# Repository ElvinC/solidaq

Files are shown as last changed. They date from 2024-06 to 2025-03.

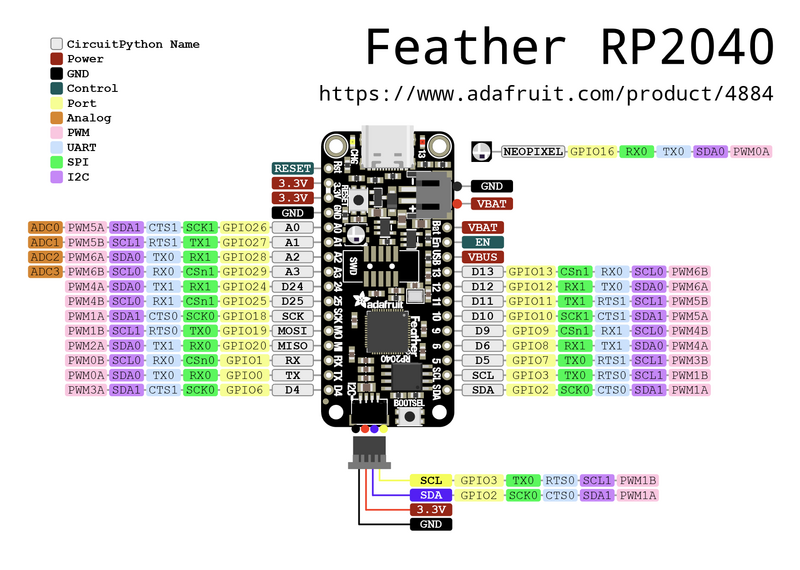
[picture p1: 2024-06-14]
Hardware/adafruit_products_feather-rp2040-pins.png

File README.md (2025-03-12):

# SoliDAQ

Super basic ADC/data logger board based on an Adafruit feather rp2040 dev board and an AD7124-4 24-bit ADC.

## Data storage format

```
typedef struct SensorLog {
    uint8_t header; // 'S' = 0x53. Keep track of used memory
    uint8_t log_id; // Log ID and marker for used memory.
    uint32_t time; // Time in ms
    int16_t adc_temp; // Cold junction temp in 0.01 deg celsius
    int16_t core_temp; // rp2040 temp in 0.01 deg celsius
    int32_t lc; // Loadcell, ratiometric in millionth (0.000001)
    int32_t tc1; // Thermocouple 1, value in nanovolts
    int32_t tc2; // Thermocouple 2, value in nanovolts
    int32_t ps; // 4-20 mA pressure. Value in nanoamps
    uint8_t delta_time;
    uint8_t log_percent; // Percent of the log that is full
    uint16_t vbat; // Battery voltage in 0.01V
} sensor_log_t;
```

csv representation example:

```
id,time[ms],tref[C],lc[mV/V],tc1[C],tc2[C],ps[mA]              
1,1374,21.0,0.670,32.8,20.7,-0.004       
```

With 32 megabytes of memory: 2.7 hours of logging time.

## USB Drive mode

The device emulates a FAT16 filesystem.

Some android phones can't open this natively. You can use e.g. the ZUGate app to connect to it.

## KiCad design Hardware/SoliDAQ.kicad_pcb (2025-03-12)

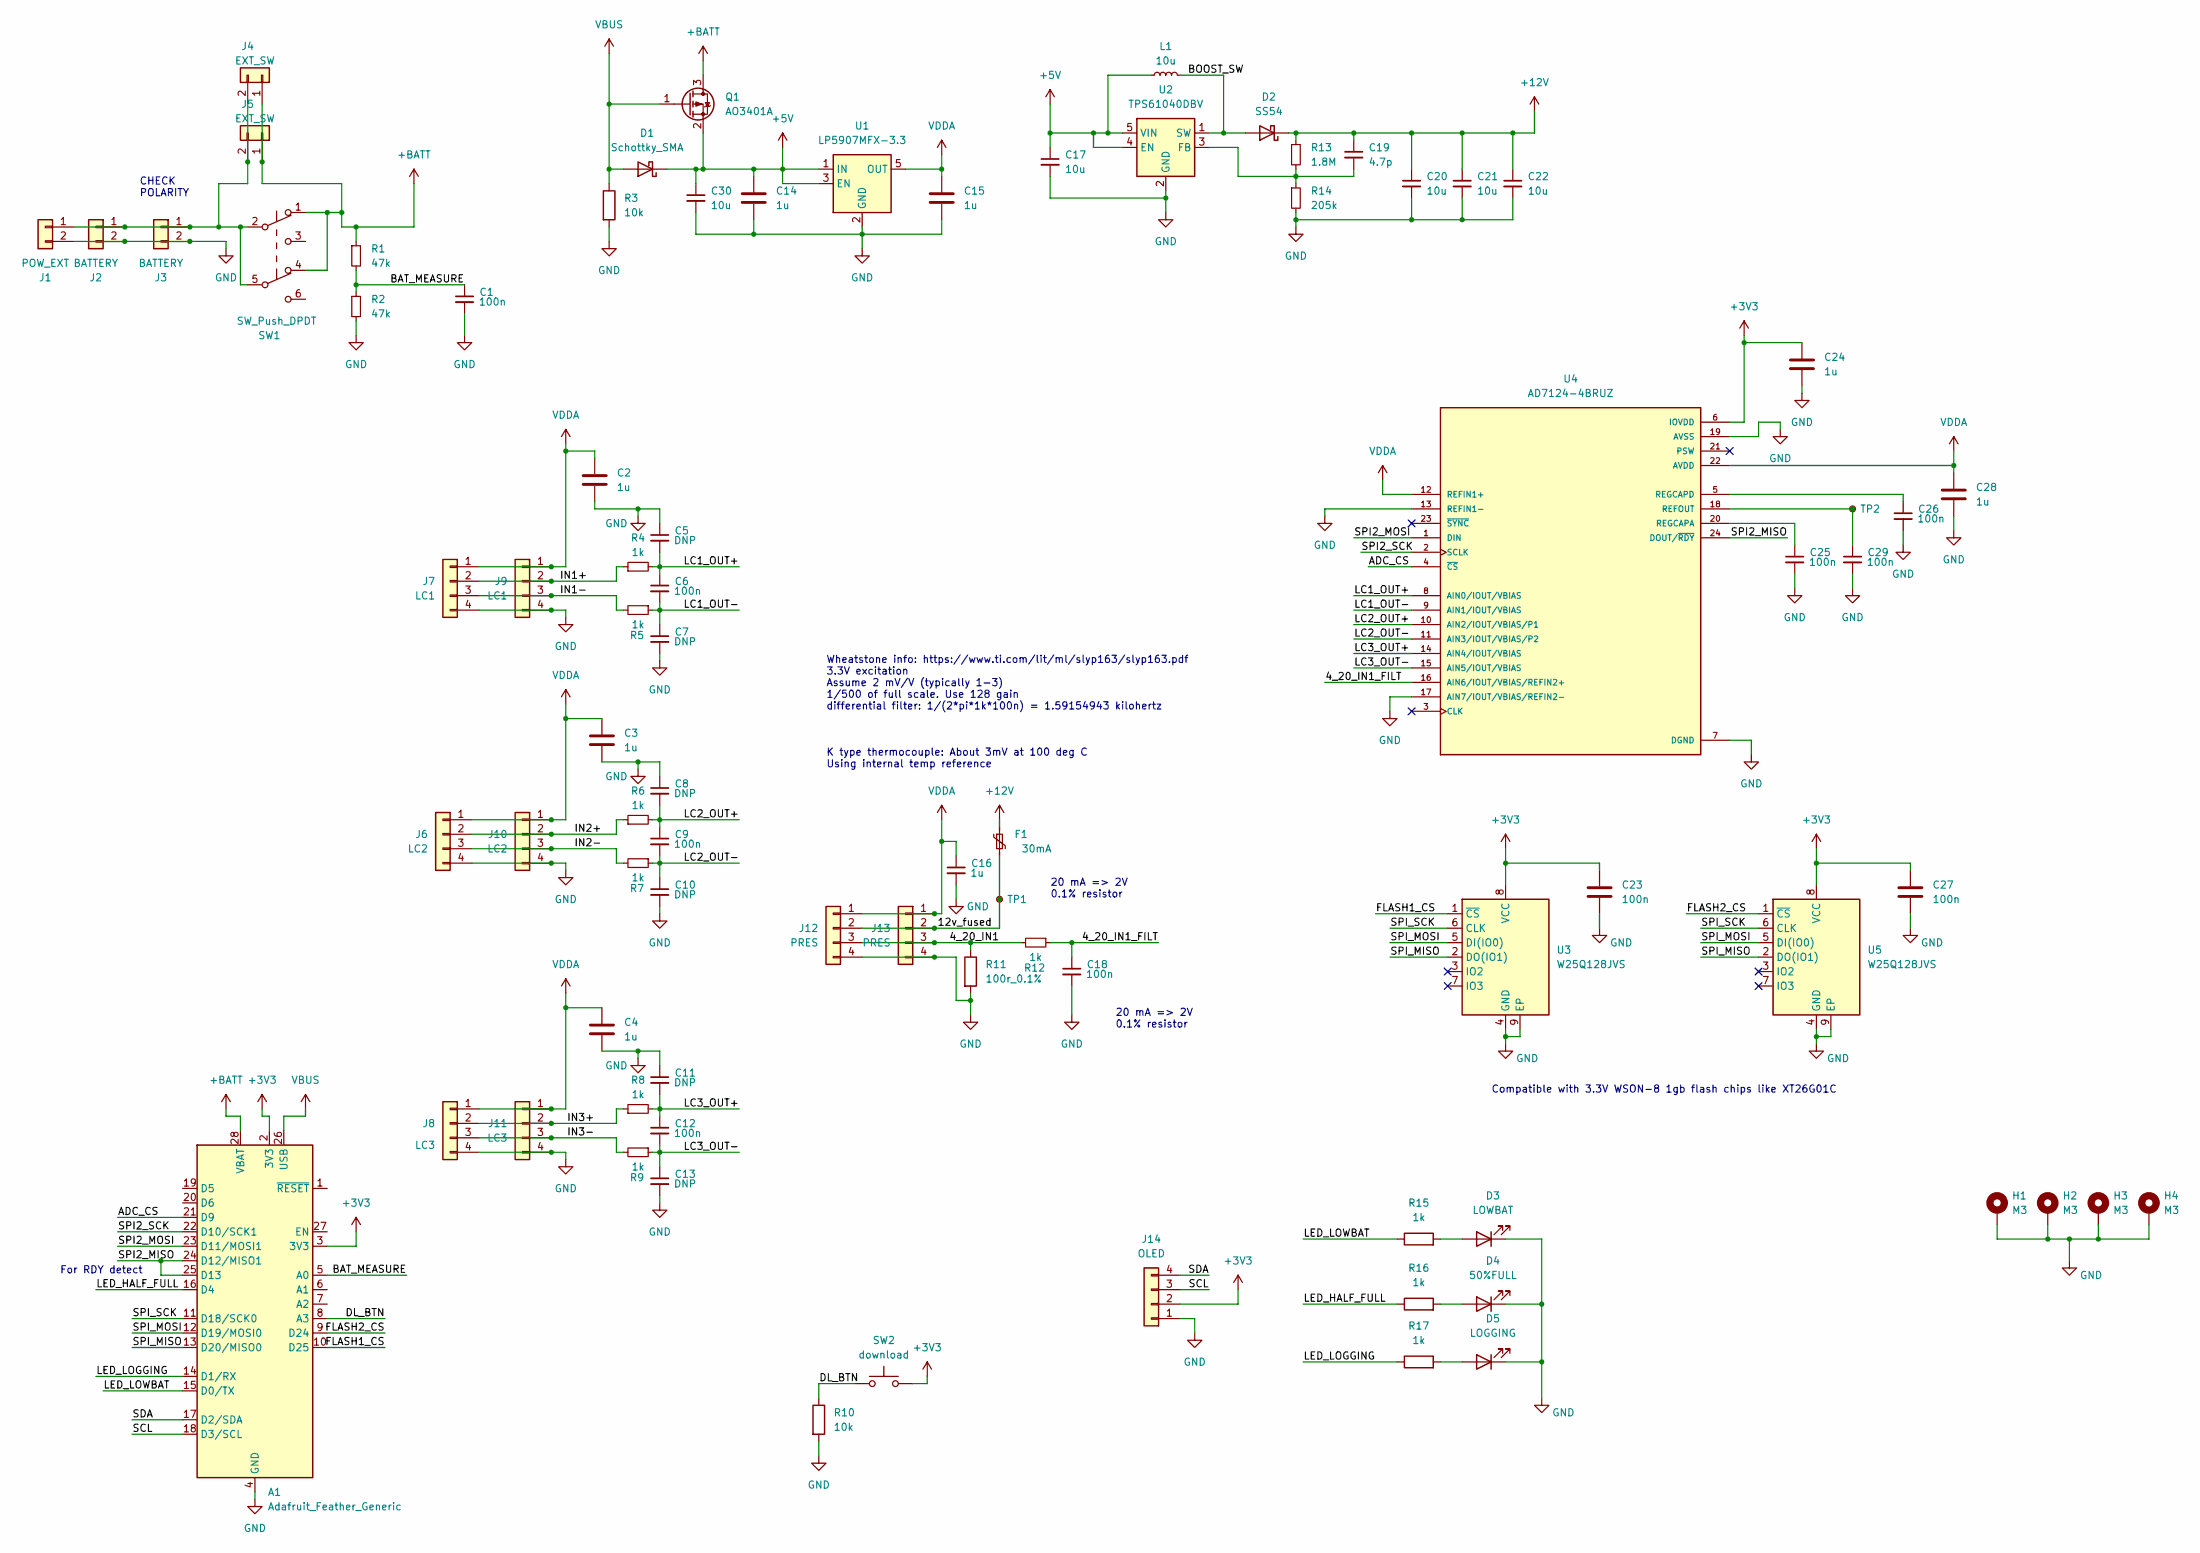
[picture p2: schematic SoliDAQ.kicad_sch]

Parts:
A1: Adafruit_Feather_Generic; Adafruit_Feather
C1, C6, C9, C12, C18, C23, C25, C26, C27, C29: 100n; C_0603_1608Metric
C2, C3, C4, C14, C15, C16, C24, C28: 1u; C_0603_1608Metric
C5, C7, C8, C10, C11, C13: DNP; C_0603_1608Metric
C17, C20, C21, C22, C30: 10u; C_0805_2012Metric
C19: 4.7p; C_0603_1608Metric
D1: Schottky_SMA; D_SMA
D2: SS54; D_SMA
D3: LOWBAT; LED_0603_1608Metric
D4: 50%FULL; LED_0603_1608Metric
D5: LOGGING; LED_0603_1608Metric
F1: 30mA; Fuse_0603_1608Metric; LCSC C7472504
H1, H2, H3, H4: M3; MountingHole_3.2mm_M3_Pad_Via
J1: POW_EXT; TerminalBlock_TE_282834-2_1x02_P2.54mm_Horizontal
J2: BATTERY; JST_PH_S2B-PH-K_1x02_P2.00mm_Horizontal
J3: BATTERY; BatteryHolder_Keystone_1042_1x18650; LCSC C2988620
J4: EXT_SW; TerminalBlock_TE_282834-2_1x02_P2.54mm_Horizontal
J5: EXT_SW; CONN2_S02B-PASK-2_JST
J6: LC2; TerminalBlock_TE_282834-4_1x04_P2.54mm_Horizontal
J7: LC1; TerminalBlock_TE_282834-4_1x04_P2.54mm_Horizontal
J8: LC3; TerminalBlock_TE_282834-4_1x04_P2.54mm_Horizontal
J9: LC1; JST_S04B-PASK-2_LF__SN_
J10: LC2; JST_S04B-PASK-2_LF__SN_
J11: LC3; JST_S04B-PASK-2_LF__SN_
J12: PRES; TerminalBlock_TE_282834-4_1x04_P2.54mm_Horizontal
J13: PRES; JST_S04B-PASK-2_LF__SN_
J14: OLED; i2c_oled
L1: 10u; L_Sunlord_MWSA0603S; LCSC C132141
Q1: AO3401A; SOT-23
R1, R2: 47k; R_0603_1608Metric
R3, R10: 10k; R_0603_1608Metric
R4, R5, R6, R7, R8, R9, R12, R15, R16, R17: 1k; R_0603_1608Metric
R11: 100r_0.1%; R_0603_1608Metric; LCSC C394538
R13: 1.8M; R_0603_1608Metric
R14: 205k; R_0603_1608Metric
SW1: SW_Push_DPDT; SW_DPDT_MST22D18G2
SW2: download; SW_Push_1P1T_XKB_TS-1187A
TP1, TP2: TestPoint_Small; TestPoint_Pad_D1.0mm
U1: LP5907MFX-3.3; SOT-23-5
U2: TPS61040DBV; SOT-23-5
U3, U5: W25Q128JVS; SOIC-8_EP_5.23x5.23mm_P1.27mm
U4: AD7124-4BRUZ; SOP65P640X120-24N; PARTREV D

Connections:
+3V3: A1.2 (3V3), A1.3 (3V3), C23.1, C24.1, C27.1, J14.2, SW2.2, U3.8 (VCC), U4.6 (IOVDD), U5.8 (VCC)
+5V: C14.1, C17.1, C30.1, D1.1 (K), L1.1, Q1.2 (S), U1.1 (IN), U1.3 (EN), U2.4 (EN), U2.5 (VIN)
+12V: C19.1, C20.1, C21.1, C22.1, D2.1 (K), F1.1, R13.1
+BATT: A1.28 (VBAT), J4.1, J5.1, Q1.3 (D), R1.1, SW1.1 (A), SW1.4 (A)
/4_20_IN1: J12.3, J13.3, R11.1, R12.2
/4_20_IN1_FILT: C18.1, R12.1, U4.16 (AIN6/IOUT/VBIAS/REFIN2+)
/12v_fused: F1.2, J12.2, J13.2, TP1.1
/ADC_CS: A1.21 (D9), U4.4 (~CS)
/BAT_MEASURE: A1.5 (A0), C1.1, R1.2, R2.1
/BOOST_SW: D2.2 (A), L1.2, U2.1 (SW)
/DL_BTN: A1.8 (A3), R10.1, SW2.1
/FLASH1_CS: A1.10 (D25), U3.1 (~CS)
/FLASH2_CS: A1.9 (D24), U5.1 (~CS)
/IN1+: J7.2, J9.2, R4.1
/IN1-: J7.3, J9.3, R5.2
/IN2+: J6.2, J10.2, R6.1
/IN2-: J6.3, J10.3, R7.2
/IN3+: J8.2, J11.2, R8.1
/IN3-: J8.3, J11.3, R9.2
/LC1_OUT+: C5.2, C6.1, R4.2, U4.8 (AIN0/IOUT/VBIAS)
/LC1_OUT-: C6.2, C7.1, R5.1, U4.9 (AIN1/IOUT/VBIAS)
/LC2_OUT+: C8.2, C9.1, R6.2, U4.10 (AIN2/IOUT/VBIAS/P1)
/LC2_OUT-: C9.2, C10.1, R7.1, U4.11 (AIN3/IOUT/VBIAS/P2)
/LC3_OUT+: C11.2, C12.1, R8.2, U4.14 (AIN4/IOUT/VBIAS)
/LC3_OUT-: C12.2, C13.1, R9.1, U4.15 (AIN5/IOUT/VBIAS)
/LED_HALF_FULL: A1.16 (D4), R16.1
/LED_LOGGING: A1.14 (D1/RX), R17.1
/LED_LOWBAT: A1.15 (D0/TX), R15.1
/SCL: A1.18 (D3/SCL), J14.3
/SDA: A1.17 (D2/SDA), J14.4
/SPI2_MISO: A1.24 (D12/MISO1), A1.25 (D13), U4.24 (DOUT/~RDY)
/SPI2_MOSI: A1.23 (D11/MOSI1), U4.1 (DIN)
/SPI2_SCK: A1.22 (D10/SCK1), U4.2 (SCLK)
/SPI_MISO: A1.13 (D20/MISO0), U3.2 (DO(IO1)), U5.2 (DO(IO1))
/SPI_MOSI: A1.12 (D19/MOSI0), U3.5 (DI(IO0)), U5.5 (DI(IO0))
/SPI_SCK: A1.11 (D18/SCK0), U3.6 (CLK), U5.6 (CLK)
GND: A1.4 (GND), C1.2, C2.2, C3.2, C4.2, C5.1, C7.2, C8.1, C10.2, C11.1, C13.2, C14.2, C15.2, C16.2, C17.2, C18.2, C20.2, C21.2, C22.2, C23.2, C24.2, C25.2, C26.2, C27.2, C28.2, C29.2, C30.2, D3.1 (K), D4.1 (K), D5.1 (K), H1.1, H2.1, H3.1, H4.1, J1.2, J2.2, J3.2, J6.4, J7.4, J8.4, J9.4, J10.4, J11.4, J12.4, J13.4, J14.1, R2.2, R3.2, R10.2, R11.2, R14.2, U1.2 (GND), U2.2 (GND), U3.4 (GND), U3.9 (EP), U4.7 (DGND), U4.13 (REFIN1-), U4.17 (AIN7/IOUT/VBIAS/REFIN2-), U4.19 (AVSS), U5.4 (GND), U5.9 (EP)
unnamed: D3.2 (A), R15.2
unnamed: D4.2 (A), R16.2
unnamed: D5.2 (A), R17.2
unnamed: J1.1, J2.1, J3.1, J4.2, J5.2, SW1.2 (B), SW1.5 (B)
unnamed: C19.2, R13.2, R14.1, U2.3 (FB)
unnamed: C29.1, TP2.1, U4.18 (REFOUT)
unnamed: C25.1, U4.20 (REGCAPA)
unnamed: C26.1, U4.5 (REGCAPD)
VBUS: A1.26 (USB), D1.2 (A), Q1.1 (G), R3.1
VDDA: C2.1, C3.1, C4.1, C15.1, C16.1, C28.1, J6.1, J7.1, J8.1, J9.1, J10.1, J11.1, J12.1, J13.1, U1.5 (OUT), U4.12 (REFIN1+), U4.22 (AVDD)

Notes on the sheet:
Compatible with 3.3V WSON-8 1gb flash chips like XT26G01C
20 mA => 2V 0.1% resistor
For RDY detect
K type thermocouple: About 3mV at 100 deg C Using internal temp reference
Wheatstone info: https://www.ti.com/lit/ml/slyp163/slyp163.pdf 3.3V excitation Assume 2 mV/V (typically 1-3) 1/500 of full scale. Use 128 gain differential filter: 1/(2*pi*1k*100n) = 1.59154943 kilohertz
CHECK POLARITY

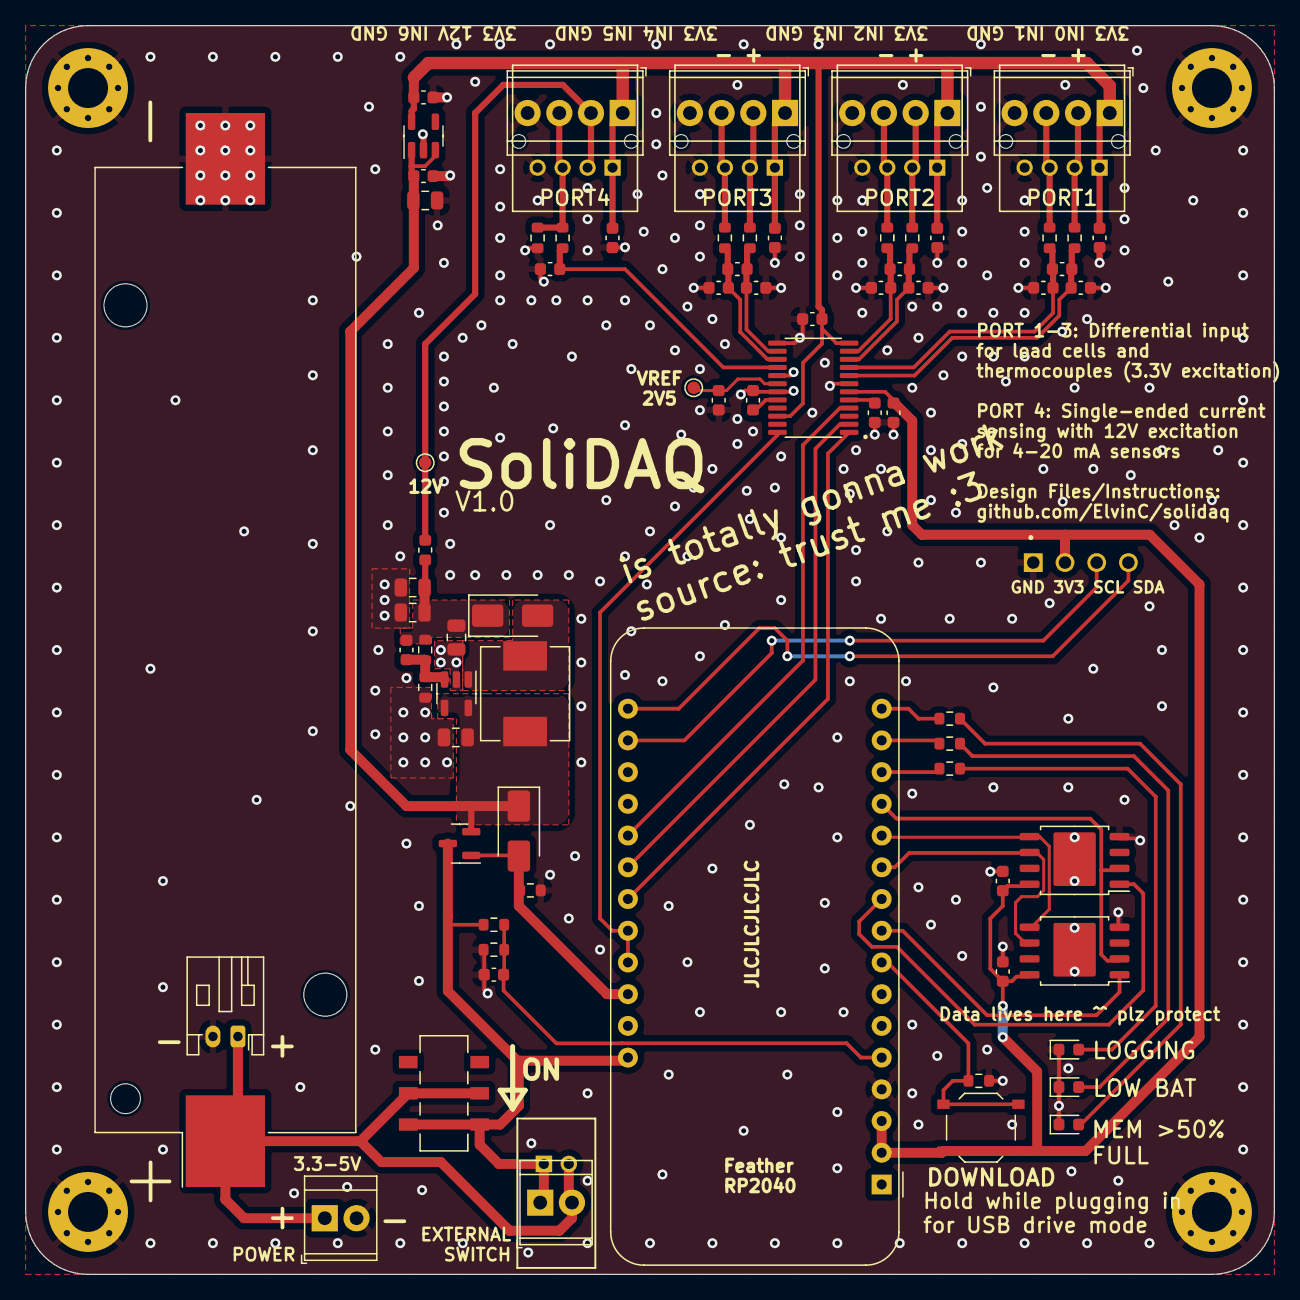
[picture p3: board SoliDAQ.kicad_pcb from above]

Board: 2 copper layers, 100.0 x 100.0 mm, 83 parts (0 on the bottom side), 47 nets.

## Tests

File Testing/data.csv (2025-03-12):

id | time[ms] | tref[C] | lc[mV/V] | tc1[C] | tc2[C] | ps[mA]
1 | 1374 | 21.0 | 0.670 | 32.8 | 20.7 | -0.004
1 | 1384 | 20.9 | 0.675 | 32.8 | 20.1 | -0.004
1 | 1394 | 21.0 | 0.679 | 32.7 | 20.7 | -0.004
1 | 1405 | 21.0 | 0.683 | 32.7 | 20.1 | -0.004
1 | 1414 | 21.0 | 0.687 | 32.5 | 20.7 | -0.004
1 | 1424 | 21.0 | 0.692 | 32.5 | 20.1 | -0.004
1 | 1434 | 21.0 | 0.696 | 32.3 | 20.7 | -0.004
1 | 1444 | 21.0 | 0.699 | 32.3 | 20.1 | -0.004
1 | 1454 | 21.0 | 0.704 | 32.1 | 20.7 | -0.004
1 | 1464 | 21.0 | 0.707 | 32.1 | 20.1 | -0.004
1 | 1474 | 21.0 | 0.711 | 31.9 | 20.7 | -0.004
1 | 1484 | 21.0 | 0.715 | 31.9 | 20.1 | -0.004
1 | 1494 | 21.0 | 0.720 | 31.7 | 20.7 | -0.004
1 | 1504 | 21.0 | 0.723 | 31.7 | 20.1 | -0.004
1 | 1514 | 21.0 | 0.727 | 31.6 | 20.7 | -0.004
1 | 1524 | 21.0 | 0.731 | 31.6 | 20.1 | -0.004
1 | 1534 | 21.0 | 0.735 | 31.4 | 20.7 | -0.004
1 | 1544 | 21.0 | 0.739 | 31.4 | 20.1 | -0.004
1 | 1554 | 21.0 | 0.743 | 31.2 | 20.7 | -0.004
1 | 1564 | 21.0 | 0.748 | 31.2 | 20.1 | -0.004
1 | 1574 | 21.0 | 0.751 | 31.0 | 20.7 | -0.004
1 | 1584 | 21.0 | 0.755 | 31.0 | 20.1 | -0.004
1 | 1594 | 21.0 | 0.759 | 30.8 | 20.7 | -0.004
1 | 1604 | 21.0 | 0.763 | 30.8 | 20.1 | -0.004
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

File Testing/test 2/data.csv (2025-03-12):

id | time[ms] | tref[C] | lc[mV/V] | tc1[C] | tc2[C] | ps[mA]
1 | 1374 | 21.5 | 0.184 | 21.2 | 10.8 | -0.004
1 | 1384 | 21.5 | 0.189 | 21.1 | 11.7 | -0.004
1 | 1394 | 21.5 | 0.193 | 21.1 | 10.6 | -0.004
1 | 1405 | 21.5 | 0.198 | 20.9 | 11.5 | -0.004
1 | 1414 | 21.5 | 0.202 | 20.9 | 10.4 | -0.004
1 | 1424 | 21.5 | 0.206 | 20.8 | 11.3 | -0.004
1 | 1434 | 21.5 | 0.210 | 20.9 | 10.2 | -0.004
1 | 1444 | 21.5 | 0.214 | 20.7 | 11.1 | -0.004
1 | 1454 | 21.5 | 0.218 | 20.8 | 10.1 | -0.004
1 | 1464 | 21.5 | 0.222 | 20.7 | 10.9 | -0.004
1 | 1474 | 21.5 | 0.226 | 20.7 | 9.9 | -0.004
1 | 1484 | 21.5 | 0.230 | 20.6 | 10.8 | -0.004
1 | 1494 | 21.5 | 0.233 | 20.7 | 9.7 | -0.004
1 | 1504 | 21.5 | 0.238 | 20.6 | 10.6 | -0.004
1 | 1514 | 21.5 | 0.241 | 20.6 | 9.5 | -0.004
1 | 1524 | 21.5 | 0.245 | 20.6 | 10.4 | -0.004
1 | 1534 | 21.5 | 0.250 | 20.6 | 9.3 | -0.004
1 | 1544 | 21.5 | 0.254 | 20.5 | 10.2 | -0.004
1 | 1554 | 21.5 | 0.258 | 20.6 | 9.1 | -0.004
1 | 1564 | 21.5 | 0.261 | 20.5 | 10.0 | -0.004
1 | 1574 | 21.5 | 0.265 | 20.6 | 8.9 | -0.004
1 | 1584 | 21.5 | 0.269 | 20.5 | 9.8 | -0.004
1 | 1594 | 21.5 | 0.273 | 20.6 | 8.7 | -0.004
1 | 1604 | 21.5 | 0.277 | 20.5 | 9.6 | -0.004
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

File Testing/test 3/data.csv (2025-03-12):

id | time[ms] | tref[C] | lc[mV/V] | tc1[C] | tc2[C] | ps[mA]
1 | 1374 | 21.5 | 0.184 | 21.2 | 10.8 | -0.004
1 | 1384 | 21.5 | 0.189 | 21.1 | 11.7 | -0.004
1 | 1394 | 21.5 | 0.193 | 21.1 | 10.6 | -0.004
1 | 1405 | 21.5 | 0.198 | 20.9 | 11.5 | -0.004
1 | 1414 | 21.5 | 0.202 | 20.9 | 10.4 | -0.004
1 | 1424 | 21.5 | 0.206 | 20.8 | 11.3 | -0.004
1 | 1434 | 21.5 | 0.210 | 20.9 | 10.2 | -0.004
1 | 1444 | 21.5 | 0.214 | 20.7 | 11.1 | -0.004
1 | 1454 | 21.5 | 0.218 | 20.8 | 10.1 | -0.004
1 | 1464 | 21.5 | 0.222 | 20.7 | 10.9 | -0.004
1 | 1474 | 21.5 | 0.226 | 20.7 | 9.9 | -0.004
1 | 1484 | 21.5 | 0.230 | 20.6 | 10.8 | -0.004
1 | 1494 | 21.5 | 0.233 | 20.7 | 9.7 | -0.004
1 | 1504 | 21.5 | 0.238 | 20.6 | 10.6 | -0.004
1 | 1514 | 21.5 | 0.241 | 20.6 | 9.5 | -0.004
1 | 1524 | 21.5 | 0.245 | 20.6 | 10.4 | -0.004
1 | 1534 | 21.5 | 0.250 | 20.6 | 9.3 | -0.004
1 | 1544 | 21.5 | 0.254 | 20.5 | 10.2 | -0.004
1 | 1554 | 21.5 | 0.258 | 20.6 | 9.1 | -0.004
1 | 1564 | 21.5 | 0.261 | 20.5 | 10.0 | -0.004
1 | 1574 | 21.5 | 0.265 | 20.6 | 8.9 | -0.004
1 | 1584 | 21.5 | 0.269 | 20.5 | 9.8 | -0.004
1 | 1594 | 21.5 | 0.273 | 20.6 | 8.7 | -0.004
1 | 1604 | 21.5 | 0.277 | 20.5 | 9.6 | -0.004
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

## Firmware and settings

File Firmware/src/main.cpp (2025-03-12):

#include <Arduino.h>

uint32_t flash_current_log_num = 0; //Update this value during initialisation

#include <UsbFileDrive.h>
#include <LittleFS.h>
#include <solidaq.h>
#include <NHB_AD7124.h>

#include <Wire.h>
#include <Adafruit_GFX.h>
#include <Adafruit_SSD1306.h>

#include <Adafruit_SPIFlash.h>

#include <pico/mutex.h>

Adafruit_SSD1306 display(128 , 64, &Wire1, -1);

#define LOGO_HEIGHT   16
#define LOGO_WIDTH    16
#define SCREEN_ADDRESS 0x3C ///< See datasheet for Address; 0x3D for 128x64, 0x3C for 128x32
static const unsigned char PROGMEM logo_bmp[] =
{ 0b00000000, 0b11000000,
  0b00000001, 0b11000000,
  0b00000001, 0b11000000,
  0b00000011, 0b11100000,
  0b11110011, 0b11100000,
  0b11111110, 0b11111000,
  0b01111110, 0b11111111,
  0b00110011, 0b10011111,
  0b00011111, 0b11111100,
  0b00001101, 0b01110000,
  0b00011011, 0b10100000,
  0b00111111, 0b11100000,
  0b00111111, 0b11110000,
  0b01111100, 0b11110000,
  0b01110000, 0b01110000,
  0b00000000, 0b00110000 };


int VBAT_PIN = A0;
// For ADC
int ADC_CS = D9;
int SPI1_SCK = D10;
int SPI1_MOSI = D11;
int SPI1_MISO = D12;
int ADC_RDY_MISO = D13; // Tied to D12;

// For flash
int SPI0_SCK = D18;
int SPI0_MOSI = D19;
int SPI0_MISO = D20;
int FLASH1_CS = D25;
int FLASH2_CS = D24;

// Misc pins
int LED_HALF_FULL = D6;
int LED_LOGGING = D1;
int LED_LOWBAT = D0;
int DOWNLOAD_PIN = A3;
int SDA_PIN = D2;
int SCL_PIN = D3;



//Adafruit_FlashTransport_SPI flashTransport(FLASH2_CS, SPI);

//Adafruit_SPIFlash flash(&flashTransport);

solidaq_flash::W25Q128 flash1;
solidaq_flash::W25Q128 flash2;


uint32_t cnt = 0;
bool okayToWrite = true;


Ad7124 adc(ADC_CS, 4000000);


/*
Channel configuration:

REF1: Load cell 3.3V


Channel 0: IN0+ IN1-: Differential load cell (Config 0)
Channel 1: IN2+ IN3-: Thermocouple (Config 1)
Channel 2: IN4+ IN5-: Thermocouple (Config 1)
Channel 3: IN6+ IN7-: 4-20 mA (100r resistor) -> 0.4 - 2V (Config 2)
Channel 4: TEMP, VSS: Internal temperature sensor (Config 3)
*/


#define CH_COUNT 5
#define CONVMODE  AD7124_OpMode_SingleConv
//#define CONVMODE  AD7124_OpMode_Continuous

uint32_t last_log_time;
uint32_t log_interval_ms = 10;
uint32_t log_counter = 0; // ID of the current log
uint32_t loop_counter = 0;
uint32_t flash2_log_start = 65536 * 8;
uint32_t max_logs = 65536 * 8 * 2; // 8 32-byte logs fit in each of the 65536 in the two flash chips. Log 524288 starts on second flash chip
uint32_t display_interval = 10; // Update display at 10 Hz

sensor_log_t current_log; // Current log for data logging purposes
uint8_t raw_log[32]; // The raw log for the memory 
sensor_log_t display_log; // Copy of current log for display on second core

// 0 = not ready
// 1 = standard display
uint8_t display_format = 0;

auto_init_mutex(display_log_mutex); // Mutex for the display log

void erase_all_flash() {
    display.clearDisplay();
    display.setTextSize(1); // Draw 2X-scale text
    display.setTextColor(SSD1306_WHITE);
    display.setCursor(10, 10);
    display.printf("Hold Download\nto confirm\nFlash Erase");
    display.display();

    while (!digitalRead(DOWNLOAD_PIN)) {
        // Wait for release
    }

    int hold_counter = 0;
    while (1) {
        if (digitalRead(DOWNLOAD_PIN)) {
            hold_counter++;
        } else {
            hold_counter = 0;
        }

        sleep_ms(1);
        if (hold_counter > 1000) {
            break;
        }
    }
    display.clearDisplay();
    display.setTextSize(1); // Draw 2X-scale text
    display.setTextColor(SSD1306_WHITE);
    display.setCursor(10, 10);
    display.printf("ERASING IN\n5 SECONDS\nUNPOWER TO ABORT");
    display.display();

    sleep_ms(5000);
    flash1.write_enable();
    sleep_ms(1);
    flash1.chip_erase();
    sleep_ms(1000);
    // Takes 40 to 200 seconds...
    uint32_t erasecounter = 0;
    while (flash1.get_busy()) {
        sleep_ms(1000);
        Serial.printf("Erasing... %ld s elapsed\n", erasecounter++);
        display.clearDisplay();
        display.setTextSize(1); // Draw 2X-scale text
        display.setCursor(10, 10);
        display.printf("Flash 1 erase\n");
        display.setCursor(10, 30);
        display.printf("%d s elapsed\n", erasecounter);
        display.display();
    }

    sleep_ms(1000);
    flash2.write_enable();
    sleep_ms(1);
    flash2.chip_erase();
    sleep_ms(1000);
    // Takes 40 to 200 seconds...
    erasecounter = 0;
    while (flash2.get_busy()) {
        sleep_ms(1000);
        Serial.printf("Erasing... %ld s elapsed\n", erasecounter++);
        display.clearDisplay();
        display.setTextSize(1); // Draw 2X-scale text
        display.setCursor(10, 10);
        display.printf("Flash 2 erase\n");
        display.setCursor(10, 30);
        display.printf("%d s elapsed\n", erasecounter);
        display.display();
    }

    display.clearDisplay();
    display.setTextSize(1); // Draw 2X-scale text
    display.setTextColor(SSD1306_WHITE);
    display.setCursor(10, 10);
    display.printf("FLASH ERASED.\nPlz restart");
    display.display();
    sleep_ms(1000);

    while(1) {

    }
};

// Make the CSV file and give it a simple header
void headerCSV()
{
    File f = LittleFS.open("data.csv", "w");
    f.printf("sample,millis,temp,rand\n");
    f.close();
    cnt = 0;
}

// Called when the USB stick connected to a PC and the drive opened
// Note this is from a USB IRQ so no printing to SerialUSB/etc.
void plug(uint32_t i)
{
    (void)i;
    okayToWrite = false;
}

// Called when the USB is ejected or removed from a PC
// Note this is from a USB IRQ so no printing to SerialUSB/etc.
void unplug(uint32_t i)
{
    (void)i;
    okayToWrite = true;
}

// Called when the PC tries to delete the single file
// Note this is from a USB IRQ so no printing to SerialUSB/etc.
void deleteCSV(uint32_t i)
{
    (void)i;
    erase_all_flash();
    //LittleFS.remove("data.csv");
    //headerCSV();
}

void setup()
{
    Serial.begin();
    sleep_ms(10);

    // Set up pins
    pinMode(VBAT_PIN, INPUT);
    pinMode(DOWNLOAD_PIN, INPUT);
    pinMode(ADC_CS, INPUT);
    pinMode(ADC_RDY_MISO, INPUT);
    pinMode(LED_HALF_FULL, OUTPUT);
    pinMode(LED_LOGGING, OUTPUT);
    pinMode(LED_LOWBAT, OUTPUT);

    pinMode(SPI0_MOSI, OUTPUT);
    pinMode(SPI0_MISO, INPUT);
    pinMode(SPI0_SCK, OUTPUT);

    // SPI for flash
    pinMode(FLASH1_CS, OUTPUT);
    digitalWrite(FLASH1_CS, HIGH);
    pinMode(FLASH2_CS, OUTPUT);
    digitalWrite(FLASH2_CS, HIGH);
    SPI.setTX(SPI0_MOSI);
    SPI.setRX(SPI0_MISO);
    SPI.setSCK(SPI0_SCK);
    SPI.begin(false);
    
    // SPI for ADC
    SPI1.setTX(SPI1_MOSI);
    SPI1.setRX(SPI1_MISO);
    SPI1.setSCK(SPI1_SCK);
    SPI1.setCS(ADC_CS);

    // I2C for OLED
    Wire1.setSCL(SCL_PIN);
    Wire1.setSDA(SDA_PIN);
    Wire1.setClock(400000);

    adc.begin(SPI1);

    flash1.init(SPI, FLASH1_CS);
    flash2.init(SPI, FLASH2_CS);

    uint8_t flash_rxbuf[256];

    if(!display.begin(SSD1306_SWITCHCAPVCC, SCREEN_ADDRESS)) {
        Serial.println(F("SSD1306 allocation failed"));
        //for(;;); // Don't proceed, loop forever
    }

    bool is_download_mode = digitalRead(DOWNLOAD_PIN);

    bool chiperase = 0;

    if (chiperase) {
        erase_all_flash();        
    } else {
        display.clearDisplay();
        display.setTextSize(2); // Draw 2X-scale text
        display.setTextColor(SSD1306_WHITE);
        display.setCursor(10, 10);
        display.printf("SoliDAQ\n");
        display.setCursor(10, 30);
        display.setTextSize(1);
        display.printf("FW: 0.1.0-alpha");
        display.setCursor(10, 50);
        display.setTextSize(1);
        if (is_download_mode) {
            display.printf("Initialising download...");
        } else {
            display.printf("Initialising...");
        }
        display.display();
        delay(300); // Pause for 2 seconds
    }


    uint32_t pagecounter = 0;
    bool flash1_available = false;
    // Check flash 1
    for (uint32_t pagenum = 0; pagenum < 65535; pagenum++) {
        // Find first empty page
        flash1.read_data(pagenum << 8, flash_rxbuf, 1);
        
        /*while (1) {
            for (int i = 0; i < 64; i++) {
                Serial.println(flash_rxbuf[i]);
            }
            Serial.println("---");
            sleep_ms(1000);
        }
        */
       pagecounter = pagenum;
        if (flash_rxbuf[0] == 0xFF) {
            flash1_available = true;
            break;
        }
    }
    
    if (!flash1_available && (pagecounter == 65534)) {
        for (uint32_t pagenum = 0; pagenum < 65535; pagenum++) {
            // Find first empty page
            flash2.read_data(pagenum << 8, flash_rxbuf, 1);
            pagecounter = pagenum + 65535;
            if (flash_rxbuf[0] == 0xFF) {
                break;
            }
        }
    }

    //while (1) {
    //    Serial.println(pagecounter);
    //    sleep_ms(1000);
    //}

    if (pagecounter == 0 && !flash1_available) {
        log_counter = max_logs;
    } else {
        log_counter = pagecounter * 8;
    }

    flash_current_log_num = log_counter;


    if (digitalRead(DOWNLOAD_PIN)) {
        // Emulate flash chip
        usbFileDrive.onDelete(deleteCSV);
        usbFileDrive.onPlug(plug);
        usbFileDrive.onUnplug(unplug);
        usbFileDrive.begin("data.csv", "data.csv");


        /*
        sleep_ms(3000);
        Serial.println("Outputting data :3");
        for (uint32_t log_num = 0; log_num < max_logs; log_num++) {
            if (log_num < flash2_log_start) {
                flash1.read_data(log_num * 32, (uint8_t *) &current_log, 32);
            } else {
                flash2.read_data((log_num - flash2_log_start) * 32, (uint8_t *) &current_log, 32);
            }

            sleep_ms(20);
            Serial.printf("#%ld, t: %ld , CH0: %f mV/V\n", log_num, current_log.time, ((double) current_log.lc) / 1000000.0);
        }
        */


        display.clearDisplay();
        display.setTextSize(2); // Draw 2X-scale text
        display.setTextColor(SSD1306_WHITE);
        display.setCursor(10, 10);
        display.printf("SoliDAQ\n");
        display.setCursor(10, 30);
        display.setTextSize(1);
        display.printf("FW: 0.1.0-alpha");
        display.setCursor(10, 50);
        display.setTextSize(1);
        display.printf("Download mode");
        display.display();
        delay(300); // Pause for 2 seconds

        while (1) {
            // Download mode
        }
    }




    // The filter select bits determine the filtering and ouput data rate
    // 1 = Minimum filter, Maximum sample rate
    // 2047 = Maximum filter, Minumum sample rate
    int filterSelBits = 6; // freq = 614.4 kHz / (32 * filterSelBits)

    adc.setAdcControl(CONVMODE, AD7124_FullPower, true);

    // Setup 0, load cell or bridges, ratiometric
    adc.setup[0].setConfig(AD7124_Ref_ExtRef1, AD7124_Gain_64, true, AD7124_Burnout_Off, 3.3);
    adc.setup[0].setFilter(AD7124_Filter_SINC3, filterSelBits);

    // Setup 1, Thermocouples
    adc.setup[1].setConfig(AD7124_Ref_Internal, AD7124_Gain_64, true);
    adc.setup[1].setFilter(AD7124_Filter_SINC3, filterSelBits);

    // Setup 2, Pressure sensor
    adc.setup[2].setConfig(AD7124_Ref_Internal, AD7124_Gain_1, true);
    adc.setup[2].setFilter(AD7124_Filter_SINC3, filterSelBits);

    // Setup 3, Internal temp
    adc.setup[3].setConfig(AD7124_Ref_Internal, AD7124_Gain_1, true);
    adc.setup[3].setFilter(AD7124_Filter_SINC3, filterSelBits);

    // Channels
    adc.setChannel(0, 0, AD7124_Input_AIN0, AD7124_Input_AIN1, true); // Loadcell
    adc.setChannel(1, 1, AD7124_Input_AIN2, AD7124_Input_AIN3, true); // Thermocouple
    adc.setChannel(2, 1, AD7124_Input_AIN4, AD7124_Input_AIN5, true); // Thermocouple
    adc.setChannel(3, 2, AD7124_Input_AIN6, AD7124_Input_AIN7, true); // Pressure
    adc.setChannel(4, 2, AD7124_Input_TEMP, AD7124_Input_AVSS, true); // Internal temp
    
    // Thermocouple bias on negative
    adc.setVBias(AD7124_VBias_AIN3,true); 
    adc.setVBias(AD7124_VBias_AIN5,true); 


    delay(1000);


   last_log_time = millis();
}


float get_vbat() {
    float vbat = analogRead(VBAT_PIN);
    return vbat / 1024.0 * 3.3 * 2.0;
}

bool get_download_btn() {
    return digitalReadFast(DOWNLOAD_PIN);
}

uint8_t flash_buffer[2048];
int32_t tc1_avg = 0.0;
int32_t tc2_avg = 0.0;
double ambient = 23.0; // Ambient temp, track glitch when less than -40 and more than 50
void loop() {

    while (millis() < last_log_time + log_interval_ms) {
        // wait
    }
    long current_time = millis();
    long delta_time = current_time - last_log_time;
    last_log_time = current_time;

    Ad7124_Readings readings[CH_COUNT];  


    adc.readVolts(readings,CH_COUNT);

    float pico_temp = analogReadTemp(3.3);

    // Apply scalings
    Serial.println(readings[2].value * 1000, 5);
    readings[4].value = adc.scaleIcTemp(readings[4].value) - 2.0; // Usually warms up slightly
    if (readings[4].value < -40 || readings[4].value > 50) {
        // Internal temp sometimes glitches, use prev value
        readings[4].value = ambient;
    }
    ambient = readings[4].value;

    readings[0].value = adc.scaleFB(readings[0].value, 3.3, 1.00);
    if (readings[1].value > 0.0206) {
        readings[1].value = 500.0;
    } else if (readings[1].value < -0.007) {
        readings[1].value = -273.0;
    } else {
        readings[1].value = adc.scaleTC(readings[1].value,readings[4].value, Type_K);
    }

    if (readings[2].value > 0.0206) {
        readings[2].value = 500.0;
    } else if (readings[2].value < -0.007) {
        readings[2].value = -273.0;
    } else {
        //readings[2].value *= 1000;
        readings[2].value = adc.scaleTC(readings[2].value,readings[4].value, Type_K);
    }
    

    //Serial.printf("CH0: %.2f mV/V, CH1: %.2f degC, CH2: %.2f degC, CH3: %.2f V, CH4: %.2f degC\n", readings[0].value, readings[1].value, readings[2].value, readings[3].value, readings[4].value);

    double lc = readings[0].value;
    double tc1 = readings[1].value;
    double tc2 = readings[2].value;
    double ps = readings[3].value * 10; // Current in mA
    double tref = readings[4].value;
    float vbat = get_vbat();

    current_log.adc_temp = (int16_t) (tref * 100.0);
    current_log.core_temp = (int16_t) (pico_temp * 100.0); // TODO: Update with pico temp
    current_log.header = 'S';
    current_log.lc = (int32_t) (lc * 1000000.0);
    current_log.log_id = 1; // Test with 1 for now. TODO
    current_log.ps = (int32_t) (ps * 1000000.0);
    current_log.tc1 = (int32_t) (tc1 * 100.0); // Temp in 0.01 deg celsius
    current_log.tc2 = (int32_t) (tc2 * 100.0);
    current_log.time = millis();
    current_log.delta_time = (uint8_t) delta_time;
    current_log.log_percent = (uint8_t) (((float)log_counter * 100) / (float)max_logs);
    current_log.vbat = (uint16_t) (vbat * 100.0);

    tc1_avg = tc1_avg * 0.95 + current_log.tc1 * 0.05;
    tc2_avg = tc2_avg * 0.95 + current_log.tc2 * 0.05;

    //sleep_us(50);
    // Write data to flash
    if (log_counter < flash2_log_start) {
        flash1.write_enable();
        sleep_us(10);
        flash1.page_program(log_counter * 32, (uint8_t*) &current_log, 32);
        //sleep_us(500); // approx flash write time
    } else if (log_counter < max_logs) {
        flash2.write_enable();
        sleep_us(10);
        flash2.page_program((log_counter - flash2_log_start) * 32, (uint8_t*) &current_log, 32);
        //sleep_us(500); // approx flash write time
         //Expected program time 434 microseconds
    }
   


    if (loop_counter % display_interval == 0) {
        Serial.printf("Log num: %ld out of %ld\n", log_counter, max_logs);
        // Update the shared variable
        if (mutex_try_enter(&display_log_mutex, 0)) {
            display_log = current_log;
            display_log.tc1 = tc1_avg;
            display_log.tc2 = tc2_avg;
            display_format = 1;
            mutex_exit(&display_log_mutex);
        }
    } 
    if (log_counter < max_logs) {
        log_counter++;
    }
    loop_counter++;

    digitalWriteFast(LED_LOGGING, (log_counter % 100) < 5);
    digitalWriteFast(LED_LOWBAT, vbat < 3.85);
    digitalWriteFast(LED_HALF_FULL, log_counter > flash2_log_start);
}

// 2nd core 
void update_display(double lc, double tc1, double tc2, double ps, double tref, float vbat,int delta_time, uint8_t log_percent) {
    display.clearDisplay();
    int log_id = 12;

    display.setTextSize(1); // Draw 2X-scale text
    display.setTextColor(SSD1306_WHITE);
    display.setCursor(0, 0);
    display.printf("%.2fV | %d%% | dt:%d\n", vbat, log_percent, delta_time);
    display.drawLine(0,8,128,8,1);
    display.setCursor(0,display.getCursorY()+3);
    display.printf("LC [mV/V]: %.3f\n", lc);
    display.setCursor(0,display.getCursorY()+2);
    display.printf("TC1 [C]: %.2f\n", tc1);
    display.setCursor(0,display.getCursorY()+2);
    display.printf("TC2 [C]: %.2f\n", tc2);
    display.setCursor(0,display.getCursorY()+2);
    display.printf("PS [mA]: %.2f\n", ps);
    display.setCursor(0,display.getCursorY()+2);
    display.printf("Tref [C]: %.2f\n", tref);
    display.display();
}

// 2nd core for display handling
void setup1() { 
    sleep_ms(1000);
}

// 2nd core for display handling
sensor_log_t core2_log;
uint8_t core2_display_format = 0;
void loop1() {
    sleep_ms(100);

    if (mutex_enter_timeout_ms(&display_log_mutex,10)) {
        core2_log = display_log;
        core2_display_format = display_format;
        mutex_exit(&display_log_mutex);
    }

    if (core2_display_format == 1) {
        double lc = ((double) core2_log.lc) / 1000000L;
        double tc1 = ((double) core2_log.tc1) / 100L;
        double tc2 = ((double) core2_log.tc2) / 100L;
        double ps = ((double) core2_log.ps) / 1000000L;
        double tref = ((double) core2_log.adc_temp) / 100L;
        float vbat = ((float) core2_log.vbat) / 100.f;
        int delta_time = (int) core2_log.delta_time;
        uint8_t log_percent = core2_log.log_percent;

        update_display(lc, tc1, tc2, ps, tref, vbat, (int) delta_time, log_percent);
    }
}
